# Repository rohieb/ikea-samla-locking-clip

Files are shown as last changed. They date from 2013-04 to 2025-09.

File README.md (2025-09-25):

IKEA SAMLA locking clip
=======================

A clip to lock the IKEA SAMLA boxes so the lid does not fall off. Based on a
[previous work](https://stratum0.org/wiki/RepRap/Modelle#SAMLA-Hook) by
\_stew\_. The length and other parameters can be adjusted.

This thing includes three versions, each implemented as a module in
`samla-locking-clip.scad`:

 * `ikea_samla_clip()` creates a plain clip without anything else,
 * `ikea_samla_clip_with_logo()` creates a version with a customizable logo
 * `ikea_samla_clip_with_text()` creates a version with customizable text.

The clip only fits for the smallest SAMLA boxes of size 5l/1gal, 11l/3gal or
22l/6gal. Sizes for larger boxes are sold by IKEA directly.

Instructions
------
After cloning this repo, first init and update the submodules:

 * `git submodule init && git submodule update`

This fetches all needed dependencies:

 * Obijuan/obiscad, used for beveling edges
 * rohieb/Write.scad, a mirror of Write.scad by HarlanDMii, used for writing
   text in OpenSCAD
 * rohieb/thing-logos, a collection of logos in DXF format

The clip itself resides as a module in `samla-locking-clip.scad`, and should be
well-documented. The file `example.scad` contains some examples on how to use
this module in OpenSCAD. You can simply render one of the provided examples by
un-commenting it (removing the `//` at the beginning of the line, be sure to
comment the other examples by prefixing the lines with `//`), or just use the
examples for customising your own version of the clip.

The STLs in this repo generally serve as an example. You can print them if you
want, but at least the _logo_ and _text_ versions are meant to be edited first
;-)

### Printing
Prints good with any layer height. If you have a logo or text, they can of
course benefit from smaller layer heights. Also no need for infill, just print
multiple perimeters. For example, with my 0.35 mm nozzle, 3 perimeters are
enough to fill the whole body of the clip and make it strong, but still with
enough clippyness.

### Post-Printing
Put the lid on your box, clip the clip on from the bottom, turning it inwards
to the top. If the clip is too tight or too lose for your box, you can heat it
slighty with a lighter, torch, blow-dryer or heat gun, clip it to your box,
then form it by hand so it fits tightly, and let it cool.

Licence
-------

This thing is licenced under CC-BY-SA-NC 3.0 Unported. For a full list of the
licensing terms, see [https://creativecommons.org/licenses/by-nc-sa/3.0/deed](https://creativecommons.org/licenses/by-nc-sa/3.0/deed).

// vim: set et ts=2 sw=2 tw=0:

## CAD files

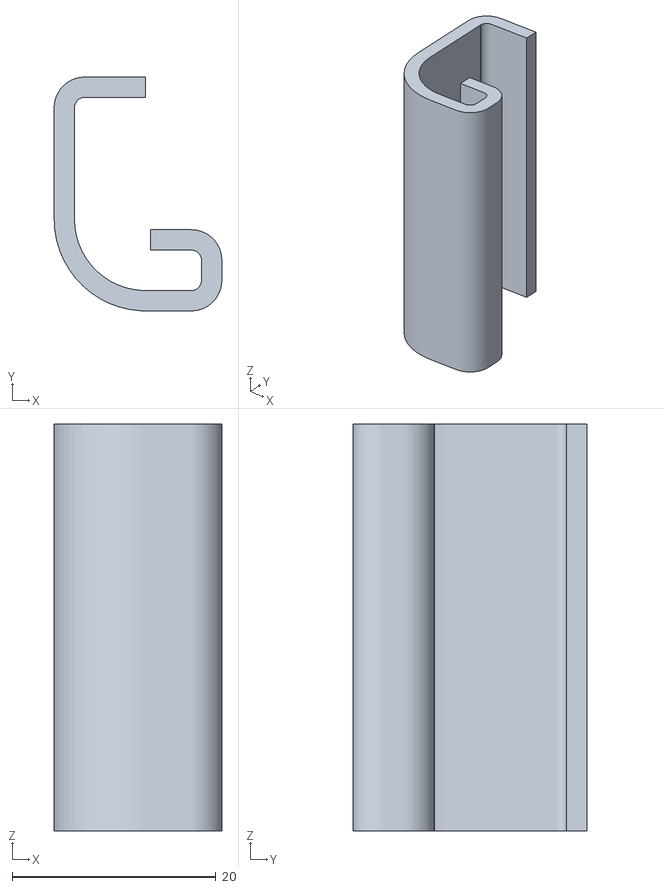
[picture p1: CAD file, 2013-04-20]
example-40mm.stl
16.5 x 23.0 x 40.0

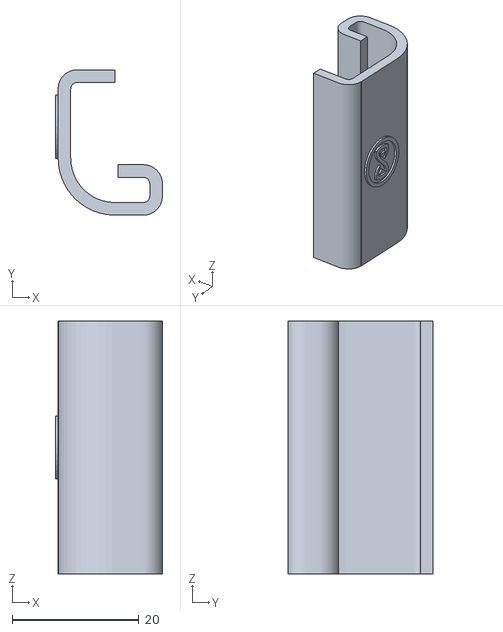
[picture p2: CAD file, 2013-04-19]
example-40mm-logo-stratum0-lowres.stl
16.9 x 23.0 x 40.0

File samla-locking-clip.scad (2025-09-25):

/**
 * A locking clip for IKEA SAMLA boxes.
 * Copyright (C) 2013 Roland Hieber <rohieb+ikeasamlaclip@rohieb.name>
 *
 * See examples.scad for examples on how to use this module.
 *
 * The contents of this file are licenced under CC-BY-NC-SA 3.0 Unported.
 * See https://creativecommons.org/licenses/by-nc-sa/3.0/deed for the
 * licensing terms.
 */

use <obiscad/obiscad/bevel.scad>
use <obiscad/obiscad/attach.scad>
use <write/Write.scad>

thickness = 2; // wall thickness
in_width = 19; // inside dimension on y axis
in_height = 12.5; // inside dimension on x axis
out_hook_length = 7; // length of outer hook segment
in_hook_length = out_hook_length-thickness; // length of inner hook segment
in_hook_offset = 4; // offset of inner hook segment on the y axis
in_big_radius = 7; // radius of the big beveled edge
in_small_radius = 1; // radius of the small beveled edges
logo_height = 2; // extrusion height of the logo

/**
 * A locking clip for IKEA SAMLA boxes.
 * Parameters:
 * length: Length of the clip. Default is 40 mm.
 */
module ikea_samla_clip(length=40) {
	$fn=50;

	// inside bevel connectors
	ci1e = [[0,0,length/2], [0,0,1], 0];
	ci1n = [ci1e[0], [-1,-1,0], 0];
	*connector(ci1e);
	*connector(ci1n);
	ci2e = [[0,in_width,length/2], [0,0,1], 0];
	ci2n = [ci2e[0], [-1,1,0], 0];
	*connector(ci2e);
	*connector(ci2n);
	ci3e = [[in_height,0,length/2], [0,0,1], 0];
	ci3n = [ci3e[0],[1,-1,0],0];
	*connector(ci3e);
	*connector(ci3n);
	ci4e = [[in_height,in_hook_offset,length/2], [0,0,1], 0];
	ci4n = [ci4e[0], [1,1,0], 0];
	*connector(ci4e);
	*connector(ci4n);

	// outside bevel connectors
	co1e = [[-thickness,-thickness,length/2], [0,0,1], 0];
	co1n = ci1n;
	*connector(co1e);
	*connector(co1n);
	co2e = [[-thickness,in_width+thickness,length/2], [0,0,1], 0];
	co2n = ci2n;
	*connector(co2e);
	*connector(co2n);
	co3e = [[in_height+thickness,-thickness,length/2], [0,0,1], 0];
	co3n = ci3n;
	*connector(co3e);
	*connector(co3n);
	co4e = [[in_height+thickness,in_hook_offset+thickness,length/2], [0,0,1], 0];
	co4n = ci4n;
	*connector(co4e);
	*connector(co4n);

	// bevel connectors for hole in inner hook
	cihhle = [[in_height-in_hook_length/2,in_hook_offset+thickness/2,length/5],
		[0,1,0], 0];
	cihhln = [cihhle[0], [1,0,-1], 0];
	*connector(cihhle);
	*connector(cihhln);
	cihhue = [[cihhle[0][0],cihhle[0][1],4*length/5], [0,1,0], 0];
	cihhun = [cihhue[0], [1,0,1], 0];
	*connector(cihhue);
	*connector(cihhun);

	difference() {
		// main body
		translate([-thickness, -thickness, 0])
			cube([in_height+2*thickness, in_width+2*thickness, length]);
		// outside radii:
		// big rounded section on the outside edge
		bevel(co1e, co1n, l=length+1, cr=in_big_radius+thickness, cres=$fn/4);
		// down-facing hook that grabs into the lid
		bevel(co2e, co2n, l=length+1, cr=in_small_radius+thickness, cres=$fn/4);
		// outside corner of the hook below the rim
		bevel(co3e, co3n, l=length+1, cr=in_small_radius+thickness, cres=$fn/4);
		// inside corner of the hook below the rim
		bevel(co4e, co4n, l=length+1, cr=in_small_radius+thickness, cres=$fn/4);

		// inner edge
		difference() {
			// bulk of the inside of the clip
			cube([in_height, in_width, length+1]);
			// big rounded section on the outside edge
			bevel(ci1e, ci1n, l=length+1, cr=in_big_radius, cres=$fn/4);
			// down-facing hook that grabs into the lid
			bevel(ci2e, ci2n, l=length+1, cr=in_small_radius, cres=$fn/4);
			// outside corner of the hook below the rim
			bevel(ci3e, ci3n, l=length+1, cr=in_small_radius, cres=$fn/4);
			// inside corner of the hook below the rim
			bevel(ci4e, ci4n, l=length+1, cr=in_small_radius, cres=$fn/4);

			// inner, upward hook
			difference() {
				translate([in_height-in_hook_length, in_hook_offset, 0])
					cube([in_hook_length, thickness, length]);
			}
		}

		// shorten the outer hook
		translate([out_hook_length, in_hook_offset+thickness, 0])
			cube([in_height, in_width, length+1]);

		// add a hole in the inner hook for the cross ribs under the boxes' rim
		if(length >= 40) {
			difference() {
				translate([in_height-in_hook_length, in_hook_offset, length/5])
					cube([in_hook_length/2, thickness, length/5*3]);
				bevel(cihhle, cihhln, l=thickness, cr=in_hook_length/2, cres=0);
				bevel(cihhue, cihhun, l=thickness, cr=in_hook_length/2, cres=0);
			}
		}
	}
}

/**
 * A locking clip for IKEA SAMLA boxes with text.
 * Parameters:
 * length: Length of the clip. Default is 40mm.
 * text: Text that is rendered on the clip
 * font: DXF font file for Write.scad
 * fontsize: font size of the text
 */
module ikea_samla_clip_with_text(length=40, text="stuff", font="orbitron.dxf", fontsize=19/2) {
	ikea_samla_clip(length=length);
	translate([-thickness, in_width-in_big_radius, length/2])
		rotate([0,-90,0])
		write(text, center=true, font=str("write/", font), h=fontsize, t=2*0.7);
}

/**
 * A locking clip for IKEA SAMLA boxes with logo.
 * Parameters:
 * length: Length of the clip. Default is 40mm.
 * logo: Path to a DXF file that is rendered as a logo on the clip. Logos should
 *  be 50mm×50mm to be rendered correctly. For a collection of logos, see
 *  https://github.com/rohieb/thing-logos
 */
module ikea_samla_clip_with_logo(length=40,
	logo="thing-logos/stratum0-lowres.dxf") {
	ikea_samla_clip(length=length);
	translate([-thickness, in_big_radius, length/2])
		scale((in_width-in_big_radius-thickness)/50)
		translate([-logo_height/2, 50, -25])
		rotate([90,0,-90])
		linear_extrude(height=logo_height, center=true)
		import(logo, center=true);
}

// vim: set sw=2 ts=2 noet:

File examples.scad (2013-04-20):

/**
 * Examples on how to use the ikea_samla_clip() module
 * Copyright (C) 2013 Roland Hieber <rohieb+ikeasamlaclip@rohieb.name>
 *
 * This file includes some examples on how to use the SAMLA clip module.
 * You can comment out one example and render it, or just use the examples to
 * learn how you can customize the clip to your own needs.
 *
 * The contents of this file are licenced under CC-BY-NC-SA 3.0 Unported.
 * See https://creativecommons.org/licenses/by-nc-sa/3.0/deed for the
 * licensing terms.
 */

use <samla-locking-clip.scad>

// one default clip with length of 40mm
// this example creates the file example-40mm.stl
ikea_samla_clip();

// one clip with a different length of 30mm
//ikea_samla_clip(length=30mm);

// clip with a default logo and default length
// this example creates the file example-40mm-logo-stratum0-lowres.stl
//ikea_samla_clip_with_logo();

// clip with different length and logo
//ikea_samla_clip_with_logo(length=30, logo="thing-logos/pesthoernchen.dxf");

// clip with a default text and default length
// this example creates the file example-40mm-text-stuff.stl
//ikea_samla_clip_with_text();

// clip with different length, text and font
//ikea_samla_clip_with_text(length=30, text="my box", font="Letters.dxf",
//	fontsize=12/2);

// vim: set sw=2 ts=2 noet:

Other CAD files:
example-40mm-text-stuff.stl

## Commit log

2013-04-08 first version
    [samla-hook.scad]
2013-04-08 adjust lengths to real neccessities
    [samla-hook.scad]
2013-04-09 separate inner and outer hook, add hole in the inner hook for the cross ribs under the boxes for lengths >= 40
    [samla-hook.scad]
2013-04-09 cleanup, final length
    [samla-hook.scad]
2013-04-09 add stratum0 logo
    [samla-hook.scad, stratum0-lowres.dxf]
2013-04-11 renamed samla-hook.scad -> samla-locking-clip.scad
    [samla-locking-clip.scad]
2013-04-11 add @Obijuan/obiscad as submodule
    [samla-locking-clip.scad]
2013-04-11 add logos as submodule
    [samla-locking-clip.scad, stratum0-lowres.dxf]
2013-04-11 add example STL with length of 40mm and stratum0-lowres logo
    [samla-locking-clip-40mm-stratum0-lowres.stl]
2013-04-11 add pre-rendered STL with length of 40mm
    [samla-locking-clip-40mm.stl]
2013-04-11 SAMLA clip with text
    [samla-locking-clip.scad]
2013-04-11 pre-rendered STL with text "stuff"
    [samla-locking-clip-40mm-text-stuff.stl]
2013-04-15 modularize: pull global variables into module scope, add one more example
    [samla-locking-clip.scad]
2013-04-16 specify license as cc-by-nc-sa-3.0 unported and add license header
    [samla-locking-clip.scad]
2013-04-16 move examples to extra file to get a nice, clean library
    [examples.scad, samla-locking-clip.scad]
2013-04-16 fix british vs. american english
    [samla-locking-clip.scad]
2013-04-19 modularize: add module ikea_samla_clip_with_logo() which uses ikea_samla_clip()
    [samla-locking-clip.scad]
2013-04-19 rename hooklength => hook_length again which was corrupted during variable moving
    [samla-locking-clip.scad]
2013-04-20 recreate example STLs and document them in examples.scad
    [example-40mm-logo-stratum0-lowres.stl, example-40mm-text-stuff.stl, example-40mm.stl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]
2013-04-20 repair whitespace, add vim modeline for example.scad
    [examples.scad, samla-locking-clip.scad]
2013-04-20 $fn should not be set at global level, but in the module itself where it is needed.
    [samla-locking-clip.scad]
2016-10-19 README: add printing and post-printing instructions
2025-09-25 improve comments in the main module
    [samla-locking-clip.scad]
